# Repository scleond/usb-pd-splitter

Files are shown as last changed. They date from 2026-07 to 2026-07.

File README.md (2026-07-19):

# USB-PD Splitter

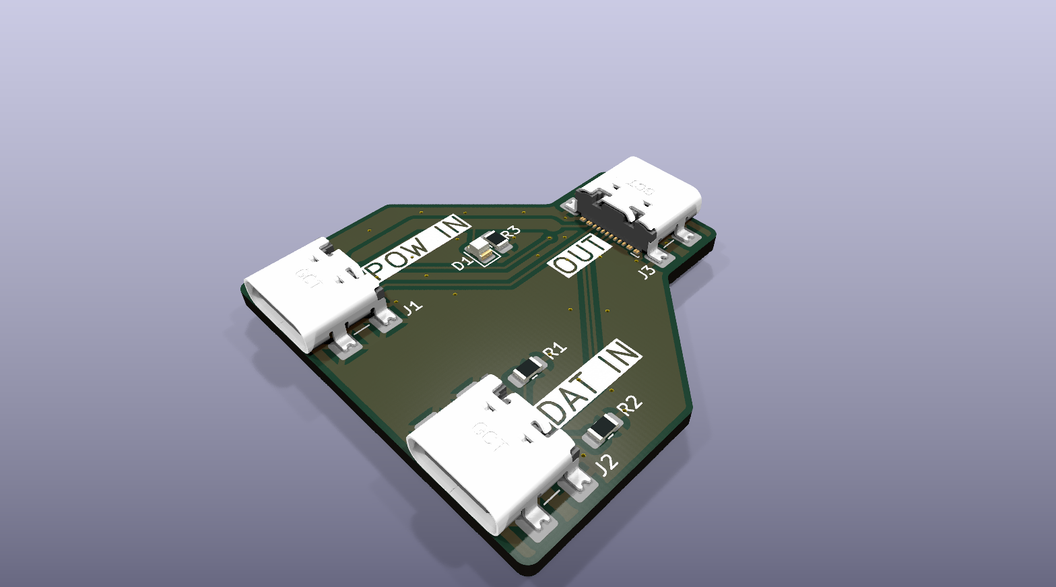
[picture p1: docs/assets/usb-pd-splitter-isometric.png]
Isometric raytraced view of the USB-PD Splitter PCB


A KiCad 10 design for a passive USB-C power/data injector: a dedicated USB-C
power input and a separate USB 2.0 data input feed one USB-C device output.

## At a glance

- `PWR_IN` supplies `VBUS`, `GND`, and CC signaling to `OUT`.
- `DATA_IN` supplies USB 2.0 `D+`, `D-`, and `GND` to `OUT`; its `VBUS` is
  isolated from the power path.
- `OUT` is the powered device connection.

This board has no USB-PD controller, data repeater, or role-switching circuit.
Its behavior must be validated with the intended power source, host, and device.

## Repository

- `usb-pd-splitter.kicad_pro`, `.kicad_sch`, and `.kicad_pcb` — KiCad sources
- `usb-pd-splitter.kicad_jobset` — native KiCad validation/export jobset
- `hardware/` — project-local symbols, footprints, and 3D models
- `automation/` — reproducible release CLI and unit tests
- `bom/` — reviewed, human-readable BOM snapshot
- `manufacturing/` — fabrication profile and release templates

Generated review and release artifacts belong in `outputs/` and `dist/`; they
are not source files.

## Documentation

- [Design notes](docs/DESIGN.md) — topology and operating assumptions
- [Requirements](docs/requirements.md) — intended interfaces and constraints
- [Connector mapping](docs/connector-mapping.md) — power, data, and CC paths
- [Release checklist](docs/manufacturing/release-process.md) — required release steps
- [Manufacturing tooling decisions](docs/manufacturing/tooling-decisions.md) — release architecture and boundaries
- [BOM guidance](bom/README.md) — tracked snapshot policy

## Release quick start

Install KiCad 10, make `kicad-cli` available on `PATH`, and install `uv`. After
changing fitted parts, refresh the snapshot and run the preflight:

```powershell
uv run --project automation hwrelease export-bom
uv run --project automation hwrelease validate
```

The formal build, JLCPCB draft placement review, packaging, tagging, and draft
publication process is documented in the [release checklist](docs/manufacturing/release-process.md).
No repository command places an order.

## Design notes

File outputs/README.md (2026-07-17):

# Generated outputs

Use this directory for plots, fabrication files, rendered schematics, and other
exports made from the KiCad source files.

Suggested subdirectories:

- `gerbers/` - Gerber copper, solder mask, silkscreen, and fabrication layers
- `drill/` - Excellon drill files
- `plots/` - PDFs, SVGs, and review renders

The generated subdirectories are ignored by Git; keep only intentionally reviewed
release artifacts under version control.

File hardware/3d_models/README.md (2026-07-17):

# 3D models

Store project-specific component models here. Keep model filenames tied to the
component part number and reference them from footprints with a project-relative
`${KIPRJMOD}` path.

Do not add models until the associated footprint and part selection are stable.

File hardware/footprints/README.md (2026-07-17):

# Custom footprints

Store project-specific KiCad footprint libraries (`.pretty` directories) here.

Use `${KIPRJMOD}/hardware/footprints` when adding this directory to the project's
footprint library table. Prefer vendor or manufacturer names in footprint-library
names when a library is specific to a part family.

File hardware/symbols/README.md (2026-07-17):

# Custom symbols

Use this folder to store KiCad schematic symbols for USB-C connectors, resistor networks, and any passive components specific to the splitter.

The current scaffold keeps its placeholder library directly in this directory:

- `usb_c.lib` - legacy-format placeholder library for USB-C and passive symbols

If the library grows, split it into focused libraries such as `usb_c/` and
`passive/`. New libraries should use KiCad's `.kicad_sym` format. The existing
placeholder library is intentionally left unchanged until the schematic symbols
are defined and tested in KiCad.

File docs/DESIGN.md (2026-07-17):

# USB-PD Splitter Design Notes

## Intended topology
- `PWR_IN`: USB-C power input
- `DATA_IN`: USB-C data input
- `OUT`: USB-C device output

## Intended signal flow
- `PWR_IN.VBUS` → `OUT.VBUS`
- `PWR_IN.GND` → `OUT.GND`
- `PWR_IN.CC1/CC2` → `OUT.CC1/CC2`
- `DATA_IN.D+` → `OUT.D+`
- `DATA_IN.D-` → `OUT.D-`
- `DATA_IN.GND` → `OUT.GND`
- `DATA_IN.CC1/CC2` present host-side signaling for the data connector
- `PWR_IN` non-CC pins DNP

## Updated design note
This design is a passive power/data injector for a USB-C device.

### What this means
- `PWR_IN` is the power input and passes `VBUS`, `GND`, and CC through to `OUT`
- `DATA_IN` is the USB host data input and passes `D+`, `D-`, `GND`, and CC signaling to `OUT`
- `OUT` is the powered device and negotiates power with the source through the power path

### Important constraint
- `DATA_IN` must present host-side CC signaling (Rp) if it is a host data connection.
- `PWR_IN` must carry `VBUS` to `OUT` or the device will have no power.

## Recommended revision
1. Route `PWR_IN.VBUS` and `PWR_IN.GND` to `OUT.VBUS` and `OUT.GND`.
2. Keep `PWR_IN.CC1/CC2` connected to `OUT.CC1/CC2` if the output device should negotiate with the power source.
3. On `DATA_IN`, use the correct CC pull resistors for the intended role:
   - If `DATA_IN` is a host-facing connector, use Rp to indicate a DFP/source.
   - If `DATA_IN` is a device-facing connector, use Rd and ensure `OUT` is actually the host side.
4. If you want a pure data-only input, consider how `DATA_IN.VBUS` will be handled for USB attachment detection and enumeration.

## Practical approach
- Make `PWR_IN` the power feed: VBUS + GND + CC only.
- Make `DATA_IN` the USB data feed: D+/D- + GND + CC as host-side signaling.
- Ensure `OUT` sees VBUS from the power source and D+/D- from the data source together.

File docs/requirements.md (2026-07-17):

# USB-PD Splitter Requirements

## Purpose
Create a passive USB-C splitter that separates power and data for a powered device.

## Connectors
- `PWR_IN`: USB-C power input
- `DATA_IN`: USB-C host data input
- `OUT`: USB-C device output

## Signal requirements
- `PWR_IN` supplies:
  - `VBUS` → `OUT.VBUS`
  - `GND` → `OUT.GND`
  - `CC1/CC2` → `OUT.CC1/CC2`
- `DATA_IN` supplies:
  - `D+` → `OUT.D+`
  - `D-` → `OUT.D-`
  - `GND` → `OUT.GND`
  - `CC1/CC2` to indicate host/data-side role
- `DATA_IN.VBUS` is not connected to `OUT`
- `PWR_IN` non-CC high-speed/data pins are DNP

## Roles
- `DATA_IN` is the USB host-side data connector
- `OUT` is the powered USB device connector
- `PWR_IN` is the power source connector
- The board is passive and does not contain an active PD controller

## Assumptions
- The power source and attached device negotiate PD independently through the `PWR_IN` → `OUT` power path.
- `DATA_IN` must present the correct CC role for a host-side data connection.
- The device on `OUT` will receive `VBUS` from `PWR_IN` and `D+/D-` from `DATA_IN`.

## KiCad
- This project is targeted for KiCad 10.
- Custom symbols and footprints will be stored under `hardware/symbols/` and `hardware/footprints/`.

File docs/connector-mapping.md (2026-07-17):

# USB-PD Splitter Connector Mapping

## Connectors

- `PWR_IN` — USB-C power input
- `DATA_IN` — USB-C host data input
- `OUT` — USB-C powered device output

## Power path

- `PWR_IN.VBUS` → `OUT.VBUS`
- `PWR_IN.GND` → `OUT.GND`
- `PWR_IN.CC1` → `OUT.CC1`
- `PWR_IN.CC2` → `OUT.CC2`

### Notes
- `PWR_IN` is the only source of power for `OUT`
- All other power/data pins on `PWR_IN` are Do Not Populate (DNP)
- `OUT` must receive CC negotiation for PD through the power path

## Data path

- `DATA_IN.D+` → `OUT.D+`
- `DATA_IN.D-` → `OUT.D-`
- `DATA_IN.GND` → `OUT.GND`
- `DATA_IN.CC1` / `DATA_IN.CC2` present host-side signaling to the host connector

### Notes
- `DATA_IN.VBUS` is not connected to `OUT`
- The data connector is a host-side interface, so CC should indicate a downstream-facing port source

## Pin usage summary

| Connector | Pin group | Usage |
| --- | --- | --- |
| `PWR_IN` | `VBUS`, `GND`, `CC1`, `CC2` | Connected to `OUT` |
| `PWR_IN` | USB 2.0/3.0 data pins | DNP |
| `DATA_IN` | `D+`, `D-`, `GND` | Connected to `OUT` |
| `DATA_IN` | `CC1`, `CC2` | Host-side role signaling |
| `DATA_IN` | `VBUS` | Isolated / not connected to `OUT` |
| `OUT` | `VBUS`, `GND`, `CC1`, `CC2`, `D+`, `D-` | Connected to power and data paths as above |

## Design caution
- This topology is passive, so it relies on the attached power source and attached device to negotiate PD correctly.
- The host connected to `DATA_IN` must see a correct host CC presentation, or USB enumeration may fail.
- If the connected device on `OUT` expects a different role on `D+`/`D-`, the passive split may require active switching or a repeater.

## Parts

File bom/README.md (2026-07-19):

# Bill of materials

Store reviewed, human-readable BOM exports here. Prefer a filename that identifies
the schematic revision or release, for example `usb-pd-splitter-r0.csv`.

Refresh the tracked snapshot with `uv run --project automation hwrelease export-bom`
after a fitted-part change. `hwrelease validate` rejects a stale snapshot.

Machine-generated or temporary exports that do not belong in version control should
go under `outputs/` instead.

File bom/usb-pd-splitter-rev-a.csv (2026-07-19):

Quantity | References | Value | Footprint | Manufacturer | MPN | LCSC Part # | JLCPCB Class | Population
1 | D1 | Green | LED_SMD:LED_0805_2012Metric | Foshan NationStar Optoelectronics | NCD0805C1 | C84257 | Extended | Fitted
3 | J1,J2,J3 | USB_C_Receptacle_USB2.0_14P | cl_Connector_USB:USB_C_Receptacle_GCT_USB4110 | Global Connector Technology | USB4110-GF-A | C5143397 | Extended | Fitted
2 | R1,R2 | 5.1k | Resistor_SMD:R_0805_2012Metric_Pad1.20x1.40mm_HandSolder | UNI-ROYAL | 0805W8F5101T5E | C27834 | Basic | Fitted
1 | R3 | 10k | Resistor_SMD:R_0805_2012Metric_Pad1.20x1.40mm_HandSolder | UNI-ROYAL | 0805W8F1002T5E | C17414 | Basic | Fitted

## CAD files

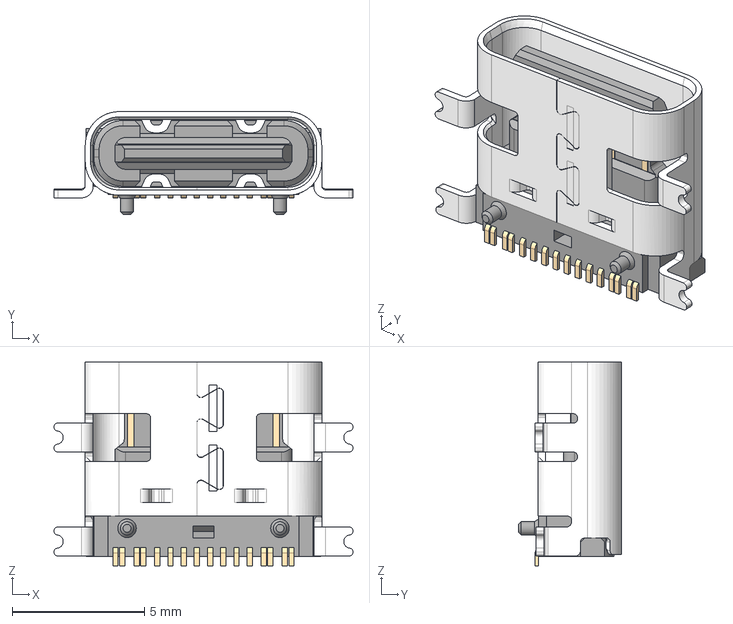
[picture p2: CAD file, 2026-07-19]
hardware/3d_models/USB4110-GF-A.stp
11.3 x 3.89 x 7.70 mm

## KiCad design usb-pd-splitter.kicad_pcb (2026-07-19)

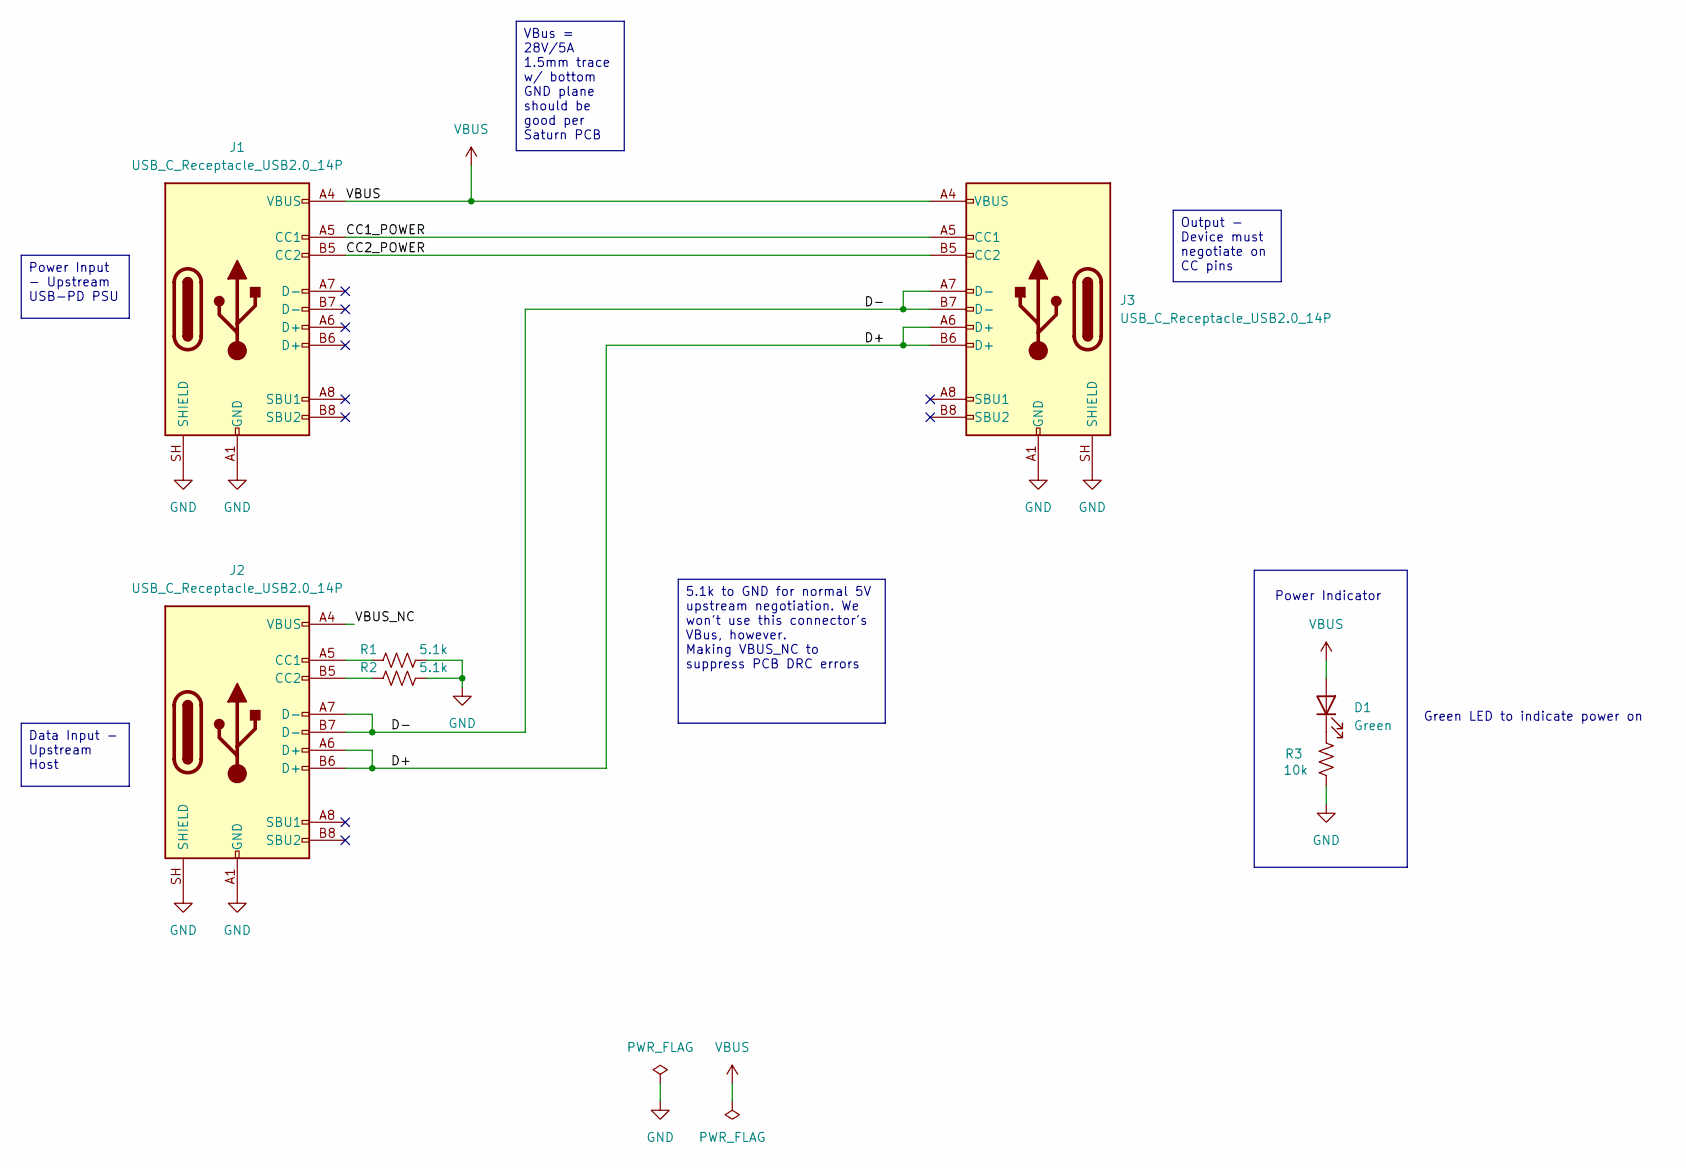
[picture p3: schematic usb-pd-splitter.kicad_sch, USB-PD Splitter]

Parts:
D1: Green; LED_0805_2012Metric; MPN NCD0805C1; LCSC Part # C84257
J1, J2, J3: USB_C_Receptacle_USB2.0_14P; USB_C_Receptacle_GCT_USB4110; MPN USB4110-GF-A; LCSC Part # C5143397
R1, R2: 5.1k; R_0805_2012Metric_Pad1.20x1.40mm_HandSolder; MPN 0805W8F5101T5E; LCSC Part # C27834
R3: 10k; R_0805_2012Metric_Pad1.20x1.40mm_HandSolder; MPN 0805W8F1002T5E; LCSC Part # C17414

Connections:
/CC1_POWER: J1.A5 (CC1), J3.A5 (CC1)
/CC2_POWER: J1.B5 (CC2), J3.B5 (CC2)
/D+: J2.A6 (D+), J2.B6 (D+), J3.A6 (D+), J3.B6 (D+)
/D-: J2.A7 (D-), J2.B7 (D-), J3.A7 (D-), J3.B7 (D-)
/VBUS_NC: J2.A4 (VBUS), J2.A9 (VBUS), J2.B4 (VBUS), J2.B9 (VBUS)
GND: J1.A1 (GND), J1.A12 (GND), J1.B1 (GND), J1.B12 (GND), J1.SH (SHIELD), J2.A1 (GND), J2.A12 (GND), J2.B1 (GND), J2.B12 (GND), J2.SH (SHIELD), J3.A1 (GND), J3.A12 (GND), J3.B1 (GND), J3.B12 (GND), J3.SH (SHIELD), R1.1, R2.1, R3.2
unnamed: D1.1 (K), R3.1
unnamed: J2.A5 (CC1), R1.2
unnamed: J2.B5 (CC2), R2.2
VBUS: D1.2 (A), J1.A4 (VBUS), J1.A9 (VBUS), J1.B4 (VBUS), J1.B9 (VBUS), J3.A4 (VBUS), J3.A9 (VBUS), J3.B4 (VBUS), J3.B9 (VBUS)

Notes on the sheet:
Power Indicator
Green LED to indicate power on
Output - Device must negotiate on CC pins
Data Input - Upstream Host
Power Input - Upstream USB-PD PSU
VBus = 28V/5A 1.5mm trace w/ bottom GND plane should be good per Saturn PCB
5.1k to GND for normal 5V upstream negotiation. We won't use this connector's VBus, however. Making VBUS_NC to suppress PCB DRC errors

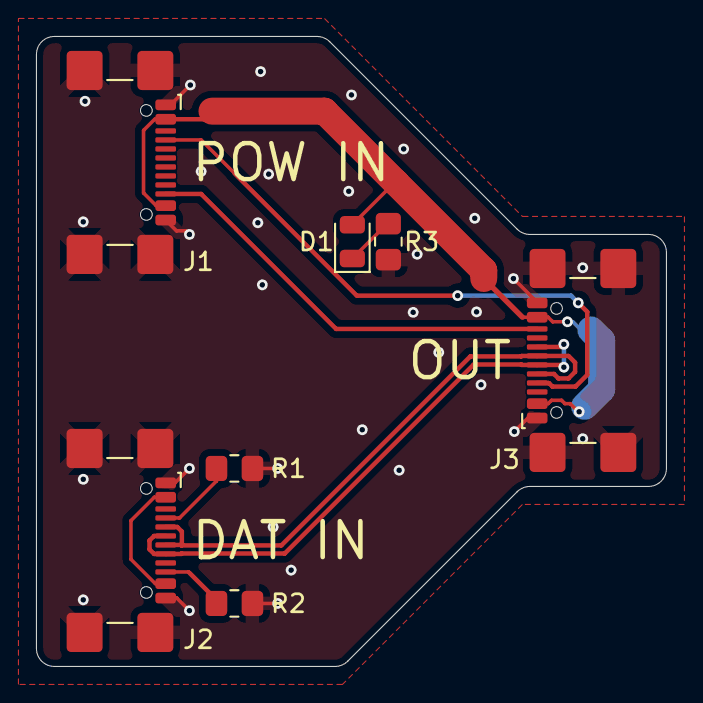
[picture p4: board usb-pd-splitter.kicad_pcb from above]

Board: 2 copper layers, 35.0 x 35.0 mm, 7 parts (0 on the bottom side), 10 nets.

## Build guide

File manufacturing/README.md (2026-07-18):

# Manufacturing workflow

The KiCad project is the source of truth. Run the release tooling from the repository root:

```powershell
uv run --project automation hwrelease validate
uv run --project automation hwrelease build
uv run --project automation hwrelease inspect
```

Formal releases omit `--allow-dirty`, use a clean commit, and are tagged as
`hardware-vMAJOR.MINOR.PATCH`. Generated packages live under `dist/` and are not
committed. A development build may use `--allow-dirty`; `--allow-warnings` exists
only for diagnosis and is recorded in the manifest.

The checked-in `.kicad_jobset` is the native GUI/CLI fallback and can be run from
KiCad's Jobsets dialog or with:

```powershell
kicad-cli jobset run --stop-on-error --file usb-pd-splitter.kicad_jobset `
  --output "Local release staging" usb-pd-splitter.kicad_pro
```

## Population policy

All components are fitted unless their KiCad DNP attribute is set. A component
intended for hand assembly must be DNP. The release tool compares the fitted
schematic references against the JLCPCB BOM and CPL.

## First-article requirement

Before ordering, upload the generated Gerber, BOM, and CPL as a draft order.
Check every JLCPCB part match, polarity, rotation, and centroid. Record confirmed
exceptions in KiCad using `JLCPCB Rotation Offset`, `JLCPCB Position Offset`, or
`JLCPCB Layer Override`; never hand-edit the release CSV as the lasting fix.

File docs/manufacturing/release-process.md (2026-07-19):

# Hardware release process

Use this checklist for every hardware release. The workflow below is organized into a simple sequence: prepare the design, validate it, review manufacturing outputs, package the release, and publish it.

## 1. Prepare the design

- Update the KiCad title-block revision and `HW_VERSION` project variable.
- Confirm every fitted part has Manufacturer, MPN, and LCSC Part # in both schematic and PCB metadata.
- Mark every hand-assembled component as DNP.
- Save the schematic, update the PCB from the schematic, refill zones, and save again.

## 2. Validate the design

- Run `uv run --project automation hwrelease export-bom` after any fitted-part change.
- Run `uv run --project automation hwrelease validate` until all metadata gates pass.
- Run the native KiCad jobset to generate local review outputs, and run ERC/DRC with schematic parity; resolve every non-excluded finding. The formal builder performs the parity check.
- Review the front/back assembly PDFs and STEP model in `outputs/jobset/`, then review their formal-build counterparts in `dist/<release>/assembly/` and `dist/<release>/mechanical/`.
- Add board-specific drawing notes in PCB Editor on `Dwgs.User` or `Cmts.User` so they appear in the PDFs.

## 3. Prepare for release

- Commit the complete design.
- Run `uv run --project automation hwrelease build` from a clean tree.
- Run `uv run --project automation hwrelease inspect`, verify checksums, and compare the BOM/CPL with Fabrication Toolkit.
- Optionally generate InteractiveHtmlBom for internal review or hand-assembly guidance.

## 4. Review manufacturing data

- Perform a draft JLCPCB upload and resolve every match, centroid, side, and rotation warning.
- Review the BOM, CPL, and placement preview before approving the upload.

## 5. Package and publish

- Run `uv run --project automation hwrelease package` to create the complete release archive and checksum.
- Tag and push the approved commit as `hardware-vX.Y.Z`.
- After `gh auth login`, create a guarded draft with `uv run --project automation hwrelease publish --draft --placement-reviewed`.
- Inspect every GitHub asset, then publish the draft explicitly in GitHub or with `gh release edit hardware-vX.Y.Z --draft=false --latest`.

## 6. Follow up after release

- Inspect and document the first article before approving repeat builds.

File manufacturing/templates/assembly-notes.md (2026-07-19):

# Assembly notes

- Populate every non-DNP reference in the released BOM and CPL.
- Do not populate references marked DNP in KiCad or the assembly drawings.
- USB-C connectors J1-J3 are GCT USB4110-GF-A (JLCPCB C5143397).
- D1 is a green NationStar NCD0805C1 LED (JLCPCB C84257).
- R1-R2 are 5.1 kOhm, 1%, 0805 UNI-ROYAL 0805W8F5101T5E (C27834).
- R3 is a 10 kOhm, 1%, 0805 UNI-ROYAL 0805W8F1002T5E (C17414).
- Verify connector shell seating, coplanarity, and all fine-pitch solder joints.
- Clean flux residue and inspect for bridges before electrical test.

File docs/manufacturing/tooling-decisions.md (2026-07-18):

# Manufacturing tooling decisions

Reviewed 2026-07-18 for KiCad 10 and JLCPCB assembly.

## Selected architecture

1. KiCad files are the single source of truth for design, population, and sourcing.
2. The native `.kicad_jobset` is the transparent GUI/CLI export fallback.
3. The repository-local `hwrelease` Python CLI is the reproducible release gate and
   packager. It invokes `kicad-cli`; it does not reimplement Gerber or drill plotting.
4. JLCPCB Fabrication Toolkit is an independent pre-order cross-check, not the sole
   release generator. Compare its BOM/CPL and the JLCPCB upload preview to the release.
5. InteractiveHtmlBom is optional internal documentation for visual inspection and
   hand assembly. It is not a fabrication source file.
6. Generated artifacts stay in ignored `outputs/` and `dist/`; the package manifest,
   source hashes, and `SHA256SUMS` provide traceability.

The Python gate is authoritative for schematic parity. KiCad 10.0.4's jobset DRC can
report that it cannot fetch a schematic netlist while still returning job success;
the jobset therefore runs ordinary DRC, while `hwrelease` invokes the direct DRC CLI
with `--schematic-parity` and parses all three JSON result sections.

KiCad 10 supports reusable jobsets and first-party command-line ERC, DRC, Gerber,
position, BOM, PDF, STEP, IPC-2581, ODB++, and related exports:
https://docs.kicad.org/10.0/en/cli/cli.html

JLCPCB's KiCad 10 guidance recommends Fabrication Toolkit for a one-click JLC-ready
cross-check and documents the required BOM/CPL columns:
https://jlcpcb.com/help/article/how-to-generate-the-bom-and-centroid-file-from-kicad

Fabrication Toolkit:
https://github.com/bennymeg/Fabrication-Toolkit

InteractiveHtmlBom:
https://github.com/openscopeproject/InteractiveHtmlBom

## Python boundary

Python owns policy that KiCad does not: metadata completeness, revision agreement,
clean-tree enforcement, DNP population rules, BOM/CPL reference parity, JLC column
mapping, normalized 0-359 degree rotations, package naming, manifests, and checksums.
The standard library is sufficient at runtime, and `uv` provides a reproducible entry
point on Windows, macOS, and Linux.
Native KiCad X/Y placement coordinates are preserved; JLCPCB's documented KiCad 10
workflow accepts the native coordinate data after column mapping. The mandatory draft
upload remains the final centroid/orientation check.

## AI and MCP boundary

Community MCP servers now cover KiCad analysis, editing, validation, and exports, but
they differ in file-format strategy, KiCad/Python coupling, and maturity. Candidates
worth reevaluating before adoption include:

- `mixelpixx/KiCAD-MCP-Server` for broad KiCad/JLC workflows.
- `Seeed-Studio/kicad-mcp-server` for KiCad Python/API-oriented inspection and edits.
- `oaslananka-lab/kicad-mcp-pro` for profile-based validation/export workflows.
- `rjwalters/kicad-tools` for standalone parsing and transactional agent sessions.

No MCP server is part of the release trust boundary today. Agents should call the same
checked-in validation/build commands as humans, work only inside the repository, and
leave ordering, release tags, warning exclusions, and placement-preview approval to a
human. This keeps future MCP adoption interchangeable instead of coupling the template
to one fast-moving community server.

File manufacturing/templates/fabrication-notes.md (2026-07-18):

# Fabrication notes

- Two-layer 1.6 mm FR-4, 1 oz copper.
- Green solder mask and white silkscreen.
- Lead-free ENIG surface finish.
- Fabricate from the supplied Gerber X2/Excellon package.
- Board outline is defined only by `Edge.Cuts`.
- Do not scale, reinterpret, or regenerate manufacturing data.
- Resolve discrepancies against the release manifest before fabrication.

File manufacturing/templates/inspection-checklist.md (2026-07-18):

# First-article inspection checklist

- [ ] Package revision and checksums match the approved release.
- [ ] Board dimensions, thickness, finish, mask, and silkscreen are correct.
- [ ] No opens or shorts in the fabrication netlist/electrical test.
- [ ] J1-J3 are the specified GCT connector and are fully seated.
- [ ] Connector contacts and shell tabs have complete solder joints.
- [ ] R1-R2 values and placements match the BOM.
- [ ] No unintended population of DNP references.
- [ ] VBUS is isolated from DATA_IN as designed.
- [ ] USB D+/D- continuity and absence of shorts are verified.
- [ ] Visual inspection photographs are archived with the release record.

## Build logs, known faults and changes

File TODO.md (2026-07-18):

# Manufacturing origin TODO

Goal: establish one explicit, board-relative manufacturing origin so Gerber,
drill, and component-placement outputs use the same coordinate system and fitted
component centroids do not have unexpected negative coordinates.

## 1. Define the convention

- [ ] Set KiCad's drill/place-file origin at the lower-left corner of the finished
  board outline.
- [ ] Document whether the origin is exactly on the `Edge.Cuts` corner or offset
  by a defined margin for boards without a simple rectangular outline.
- [ ] Add the origin policy and permitted coordinate tolerance to
  `manufacturing/profiles/jlcpcb.toml`.
- [ ] Treat shared-origin consistency as the release requirement; positive
  placement coordinates are a derived validation check.

## 2. Make every export use the same origin

- [ ] Update the Python release CLI to use KiCad's drill/place origin for Gerbers,
  Excellon drill files, drill maps, and native position output.
- [ ] Update `usb-pd-splitter.kicad_jobset` with the equivalent origin settings.
- [ ] Confirm IPC-2581, ODB++, IPC-D-356, PDF, and mechanical exports either use
  the same origin or clearly document why their coordinate systems differ.
- [ ] Ensure no export applies an additional unrecorded X/Y translation.

## 3. Add automated validation

- [ ] Read the configured origin and calculate the `Edge.Cuts` board bounding box.
- [ ] Require all fitted CPL references to match the fitted BOM references.
- [ ] Reject fitted centroids with X or Y below the configured rounding tolerance.
- [ ] Reject centroids outside the board bounding box, allowing a documented
  tolerance for edge-mounted connectors whose footprint origins remain on-board.
- [ ] Normalize rotations to 0-359 degrees without changing component positions.
- [ ] Add unit tests for positive coordinates, negative-coordinate rejection,
  boundary tolerances, malformed values, and top/bottom components.

## 4. Improve release traceability

- [ ] Record the manufacturing-origin coordinates, origin type, board bounds, and
  validation tolerance in `manifest.json`.
- [ ] Include a coordinate-validation summary in `hwrelease inspect`.
- [ ] Add the origin convention to fabrication and assembly notes.
- [ ] Explain how to reproduce the origin when this repository becomes a template.

## 5. Validate with actual outputs

- [ ] Regenerate the complete release package from a clean commit.
- [ ] Confirm ERC, DRC, and schematic parity remain at zero findings.
- [ ] Compare Gerber and drill alignment in KiCad Gerber Viewer.
- [ ] Compare the repository-generated CPL against Fabrication Toolkit output.
- [ ] Upload Gerber, BOM, and CPL files to a draft JLCPCB order.
- [ ] Verify every centroid, rotation, layer, and connector placement in JLCPCB's
  assembly preview before approving the convention.
- [ ] Record any required footprint-specific rotation or position corrections in
  KiCad metadata, then regenerate rather than editing the CPL manually.

## Acceptance criteria

- [ ] Gerber, drill, and CPL outputs share one documented manufacturing origin.
- [ ] All fitted component centroids pass board-bounds and coordinate checks.
- [ ] The manifest makes the coordinate system independently auditable.
- [ ] The native jobset and Python release path produce equivalent aligned data.
- [ ] A JLCPCB draft upload confirms correct placement without manual CSV edits.

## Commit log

2026-07-17 Organize KiCad project scaffold
    [usb-pd-splitter.kicad_pcb, usb-pd-splitter.kicad_sch]
2026-07-18 schematic done
    [usb-pd-splitter.kicad_sch]
2026-07-18 layout done, routing half way
    [usb-pd-splitter.kicad_pcb, usb-pd-splitter.kicad_sch]
2026-07-18 ignore all outputs
    [usb-pd-splitter.kicad_sch]
2026-07-18 routing complete, drc pass
    [usb-pd-splitter.kicad_pcb, usb-pd-splitter.kicad_sch]
2026-07-18 Add deterministic hardware release workflow and README 3D render
    [usb-pd-splitter-rev-a.csv, usb-pd-splitter.kicad_pcb, usb-pd-splitter.kicad_sch]
2026-07-19 release: prepare hardware v1.1.0
    [usb-pd-splitter.kicad_pcb, usb-pd-splitter.kicad_sch]
2026-07-19 fix: exclude review PDFs from JLCPCB Gerbers
2026-07-19 release: finalize hardware v1.1.0
    [USB4110-GF-A.stp, usb-pd-splitter.kicad_pcb]
2026-07-19 cleaned up docs
    [usb-pd-splitter-rev-a.csv]
2026-07-19 Add assembly drawing jobset exports

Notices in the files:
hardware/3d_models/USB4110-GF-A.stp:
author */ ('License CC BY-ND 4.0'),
